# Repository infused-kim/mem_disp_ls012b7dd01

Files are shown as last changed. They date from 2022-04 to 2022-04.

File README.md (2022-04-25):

# Sharp Memory Display Breakout Board for LS012B7DD01

The purpose of this board is to provide a near-drop-in low-power display replacement for the popular SSD1306 128x32 OLED.

It is meant to be used in wireless ergo split keyboards such as the [sofle](https://github.com/josefadamcik/SofleKeyboard) and [corne](https://github.com/foostan/crkbd).

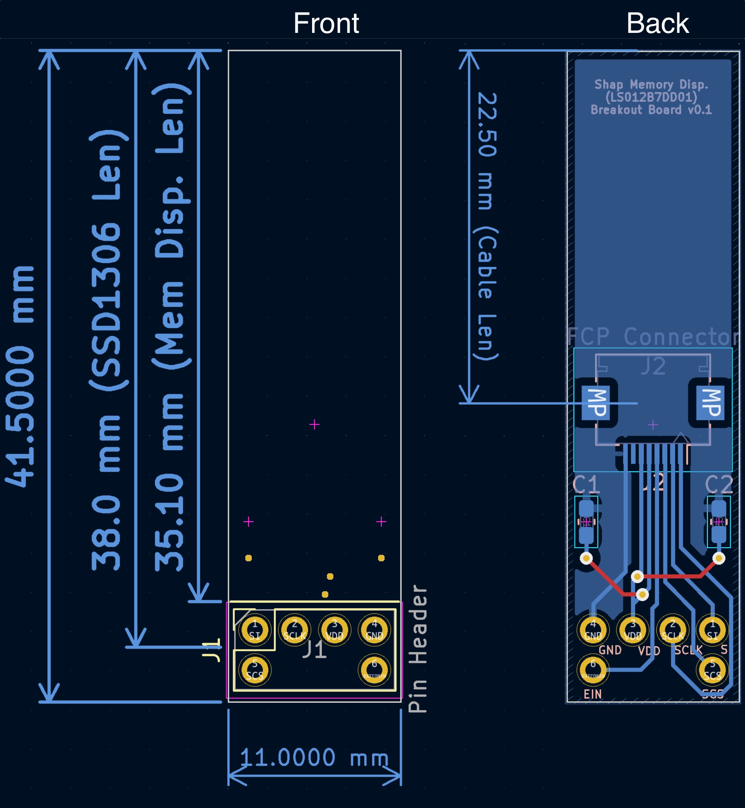
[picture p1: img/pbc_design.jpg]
PBC Image


> :warning: **Warning:**
>
> This board has not been tested yet.

## Credits

- Crehmann and [his breakout board for LS011B7DH03](https://github.com/crehmann/Sharp-Memory-LCD-Breakout), which I used as a reference and from which I drew a lot of inspiration
- Jon808517 [and his board](https://discord.com/channels/719497620560543766/785533287049330729/964635218940141569), which lead me to pursue this project
- All of the super helpful guys on the ZMK discord who patiently answered all my questions

## Related Projects

- [crehmann/Sharp-Memory-LCD-Breakout](https://github.com/crehmann/Sharp-Memory-LCD-Breakout)
- [karnadii/sharp_memory_display_breakout](https://github.com/karnadii/sharp_memory_display_breakout)
- [adafruit/Adafruit-Sharp-Memory-Display-PCBs](https://github.com/adafruit/Adafruit-Sharp-Memory-Display-PCBs)

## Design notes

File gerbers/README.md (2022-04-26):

# Gerbers for Sharp Memory Display Breakout Board for LS012B7DD01

Gerbers can be found in the [repo's releases section](../../../releases/).

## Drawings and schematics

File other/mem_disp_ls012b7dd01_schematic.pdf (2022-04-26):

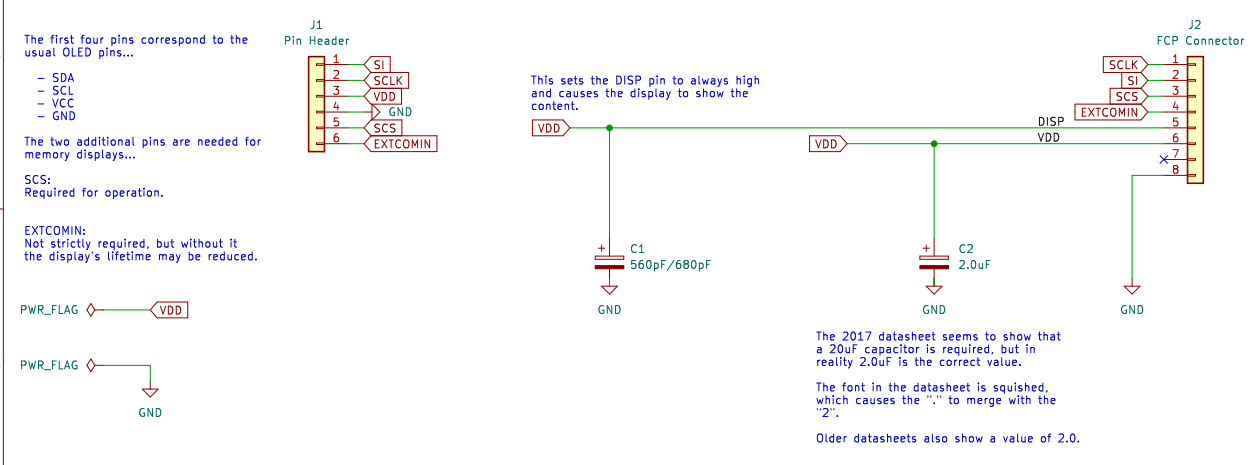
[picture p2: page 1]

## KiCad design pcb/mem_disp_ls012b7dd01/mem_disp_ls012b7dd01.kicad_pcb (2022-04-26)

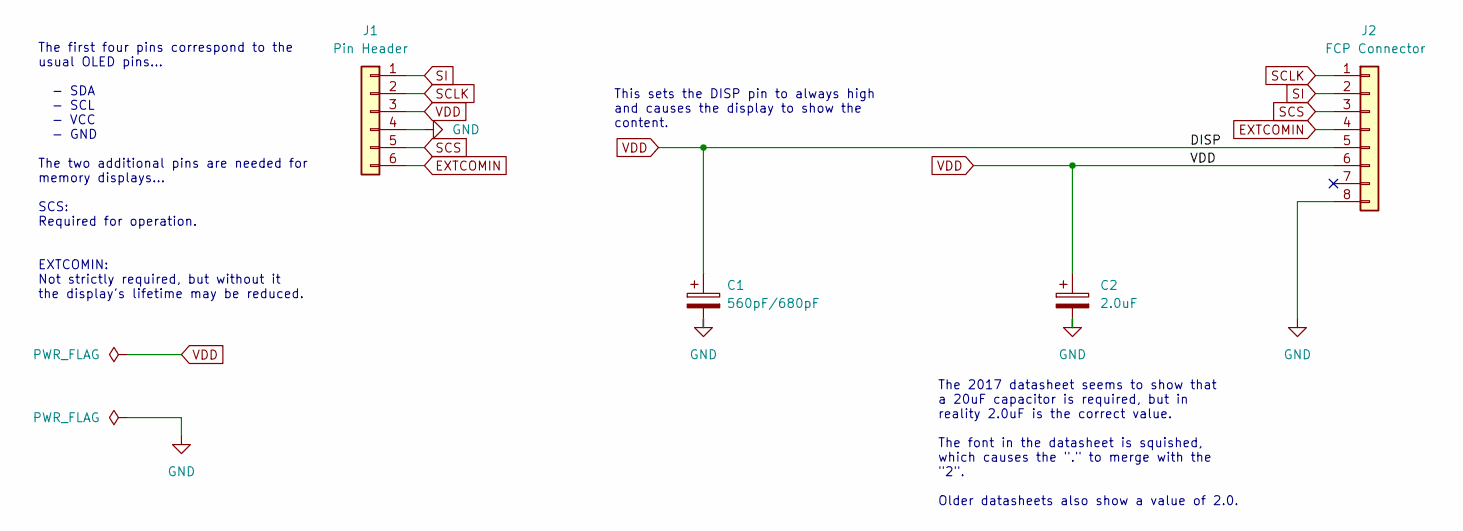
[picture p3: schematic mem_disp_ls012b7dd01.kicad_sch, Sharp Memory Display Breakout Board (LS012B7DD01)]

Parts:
C1: 560pF/680pF; C_0603_1608Metric_Pad1.08x0.95mm_HandSolder
C2: 2.0uF; C_0603_1608Metric_Pad1.08x0.95mm_HandSolder
J1: Pin Header; PinSocket_1x04_1x02_P2.54mm_Vertical
J2: FCP Connector; Hirose_FH12-8S-0.5SH_1x08-1MP_P0.50mm_Horizontal

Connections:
EXTCOMIN: J1.6, J2.4
GND: C1.2, C2.2, J1.4, J2.8
SCLK: J1.2, J2.1
SCS: J1.5, J2.3
SI: J1.1, J2.2
VDD: C1.1, C2.1, J1.3, J2.5, J2.6

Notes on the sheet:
The 2017 datasheet seems to show that a 20uF capacitor is required, but in reality 2.0uF is the correct value. The font in the datasheet is squished, which causes the "." to merge with the "2". Older datasheets also show a value of 2.0.
The first four pins correspond to the usual OLED pins... - SDA - SCL - VCC - GND The two additional pins are needed for memory displays... SCS: Required for operation. EXTCOMIN: Not strictly required, but without it the display's lifetime may be reduced.
This sets the DISP pin to always high and causes the display to show the content.

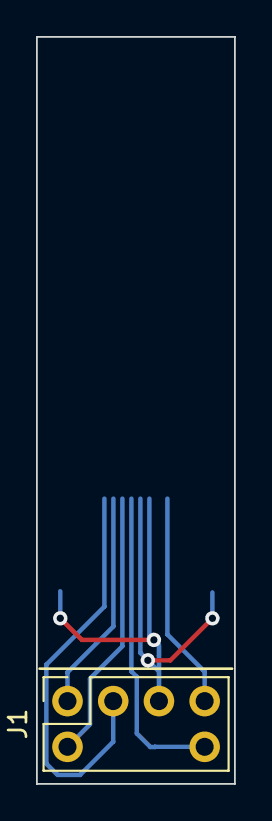
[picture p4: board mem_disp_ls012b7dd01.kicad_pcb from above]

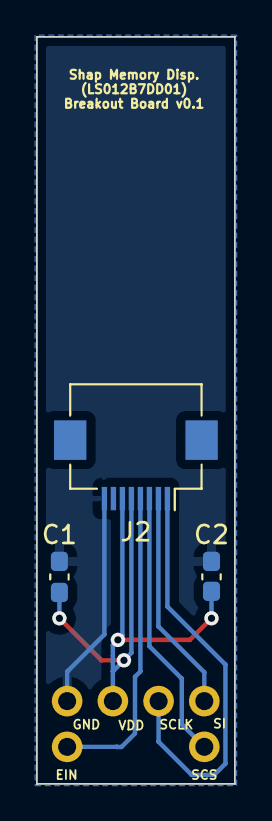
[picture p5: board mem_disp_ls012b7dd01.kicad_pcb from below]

Board: 2 copper layers, 11.0 x 41.5 mm, 4 parts (3 on the bottom side), 6 nets.

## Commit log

2022-04-25 Added initial version
    [mem_disp_ls012b7dd01.kicad_pcb, mem_disp_ls012b7dd01.kicad_sch]
2022-04-25 Fixed capacitor mix up
    VDD pin was connected to DISP capacitor and DISP capacitor was connected to VDD.
    From an electrical perspective it didn’t matter though.
    [mem_disp_ls012b7dd01.kicad_pcb, mem_disp_ls012b7dd01.kicad_sch]
2022-04-26 Fixed C1 capacity from 20uF to 2.0uF
    The 2017 datasheet seems to show that a 20uF capacitor is requiered, but in reality 2.0uF is the correct value.
    The font in the datasheet is squished, which causes the "." to merge with the
    "2".
    Older datasheets also show a value of 2.0.
    [mem_disp_ls012b7dd01.kicad_pcb, mem_disp_ls012b7dd01.kicad_sch]
2022-04-26 Added README to gerbers directory
